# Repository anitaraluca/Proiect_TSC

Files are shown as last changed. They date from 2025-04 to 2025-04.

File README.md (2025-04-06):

# Proiect_TSC

## 📊 Diagrama Block

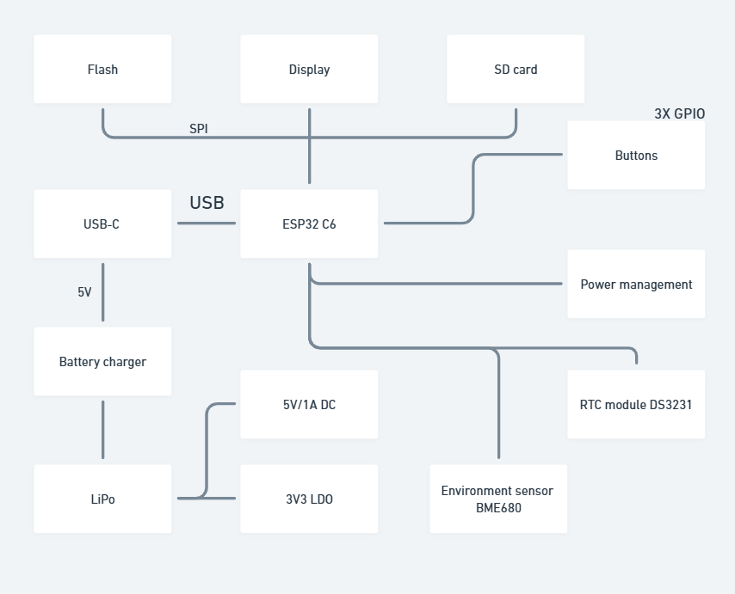
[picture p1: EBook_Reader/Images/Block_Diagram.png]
Block Diagram


---

##  Descriere Hardware

### 1. Microcontroller – ESP32-C6
- Nucleul sistemului, gestionează toate comunicațiile și logica aplicației.
- Arhitectură RISC-V 32-bit, 160 MHz
- Conectivitate: Wi-Fi 6 (2.4 GHz), Bluetooth 5.0
- GPIO: configurate pentru SPI, I2C, UART, control E-Ink

### 2. Power Management & Baterie
- Baterie Li-Po, 3.7V, 1800mAh
- Circuit de încărcare: MCP73831T
- Alimentare prin USB-C la 5V
- Protecție la supraîncărcare și descărcare profundă
- Regulator LDO 3.3V

### 3. Display – E-Ink 7.5"
- Dimensiune: 7.5 inch
- Rezoluție: 800x480 px
- Comunicare prin SPI

### 4. Port USB-C & Protecție ESD
- Alimentare și transfer de date
- Diodă Schottky și protecție ESD integrată

### 5. RTC – DS3231SN
- Păstrează ora exactă fără alimentare
- Comunicare prin I2C, include baterie de rezervă

### 6. Senzor Ambiental – BME688
- Măsoară temperatură, umiditate, presiune și calitatea aerului
- Comunicare I2C

### 7. Memorie externă – NOR Flash 64MB
- Conectată prin SPI
- Stocare extinsă pentru date și aplicații

### 8. Cititor SD Card
- Comunică prin SPI
- Permite stocare fișiere, jurnalizare și update firmware

### 9. Test Pads
- GPIO: control butoane și I/O general
- SPI: comunicare SD card, Flash și Display
- I2C: senzori și RTC
- UART: debug și serial
- Wi-Fi & Bluetooth: conectivitate wireless

---

##  Pin Mapping

| Componentă | Pini ESP32-C6 | Interfață | Funcționalitate |
|---|---|---|---|
| Butoane Control | IO9 (BOOT), IO15 (CHANGE), EN (RESET) | GPIO | Interacțiune utilizator |
| Conexiune USB-C | GPIO prin regulator | USB | Alimentare + programare ESP32 |
| Afișaj E-Paper | IO7, IO6, IO10, IO5, IO23, IO3 | SPI | Transfer date imagine + control |
| Senzor BME688 | IO21 (SDA), IO22 (SCL) | I2C | Măsurători ambientale |
| Modul RTC DS3231 | IO21 (SDA), IO22 (SCL), IO1, IO0, IO18 | I2C | Timp real |
| Flash NOR extern | IO11 (CS), IO6, IO2, IO7 | SPI | Memorie aplicație |
| Cititor MicroSD | IO7, IO6, IO4, IO2 | SPI | Stocare fișiere externe |
| Monitorizare Baterie | IO21 (SDA), IO22 (SCL) | I2C | Nivel încărcare |

---

##  Bill of Materials

| Componentă | Datasheet |  Distribuitor |
|---|---|---|
| CPH3225A | [Datasheet](https://www.snapeda.com/parts/CPH3225A/Seiko%20Instruments/datasheet/) | [Link](https://www.snapeda.com/parts/CPH3225A/Seiko+Instruments/view-part/?ref=eda) |
| TPTP20R | [Datasheet](https://cdn-shop.adafruit.com/product-files/3825/3825_diagram.PDF) | [Link](https://ro.mouser.com/ProductDetail/Adafruit/3825?qs=%252bEew9%252b0nqrAn6n76%252bB5vZg%3D%3D) |
| ESP32C6 Varistor 1812 | [Datasheet](https://www.snapeda.com/parts/RC0603JR-070RL/Yageo/datasheet/) | [Link](https://www.snapeda.com/parts/RC0603JR-070RL/Yageo/view-part/) |
| Capacitor 0402 | [Datasheet](https://componentsearchengine.com/Datasheets/2/CC0402MRX5R5BB106.pdf) | [Link](https://componentsearchengine.com/part-view/CC0402MRX5R5BB106/YAGEO) |
| USB4110-GF-A | [Datasheet](https://gct.co/files/drawings/usb4110.pdf) | [Link](https://componentsearchengine.com/part-view/USB4110-GF-A/GCT%20(GLOBAL%20CONNECTOR%20TECHNOLOGY)) |
| MBR0530 Schottky Diode | [Datasheet](https://www.snapeda.com/parts/MBR0530/ON%20Semiconductor/datasheet/) | [Link](https://www.snapeda.com/parts/MBR0530/Onsemi/view-part/?ref=eda) |
| PGB1010603MR | [Datasheet](https://www.snapeda.com/parts/PGB1010603MR/Littelfuse%20Inc./datasheet/) | [Link](https://www.snapeda.com/parts/PGB1010603MR/Littelfuse/view-part/?ref=eda) |
| MAX17048G+T10 | [Datasheet](https://www.snapeda.com/parts/MAX17048G+T10/Analog%20Devices/datasheet/) | [Link](https://www.snapeda.com/parts/MAX17048G+T10/Analog+Devices/view-part/?ref=eda) |
| QWIIC Connector | [Datasheet](https://www.snapeda.com/parts/PRT-14417/SparkFun%20Electronics/datasheet/) | [Link](https://www.snapeda.com/parts/PRT-14417/SparkFun/view-part/) |
| ESP32C6 WROOM-1-N8 | [Datasheet](https://www.snapeda.com/parts/ESP32-C6-WROOM-1-N8/Espressif%20Systems/datasheet/) | [Link](https://www.snapeda.com/parts/ESP32-C6-WROOM-1-N8/Espressif+Systems/view-part/?ref=eda) |
| RCL CPOL 3528 | [Datasheet](https://s3.amazonaws.com/snapeda/datasheet/TAJB475K025RNJ_AVX.pdf) | [Link](https://www.snapeda.com/parts/TAJB475K025RNJ/AVX/view-part/?ref=dk&t=capacitor%203528&con_ref=None) |
| 744043680 | [Datasheet](https://www.we-online.com/components/products/datasheet/744043680.pdf) | [Link](https://ro.mouser.com/ProductDetail/Wurth-Elektronik/744043680?qs=PGXP4M47uW6VkZq%252BkzjrHA%3D%3D) |
| SI1308EDL-T1-GE3 MOSFET | [Datasheet](https://www.snapeda.com/parts/SI1308EDL-T1-GE3/Vishay%20Siliconix/datasheet/) | [Link](https://www.snapeda.com/parts/SI1308EDL-T1-GE3/Vishay+Siliconix/view-part/?ref=eda) |
| DS3231SN | [Datasheet](https://www.snapeda.com/parts/DS3231SN%23/Analog%20Devices/datasheet/) | [Link](https://www.snapeda.com/parts/DS3231SN%23/Analog+Devices/view-part/?ref=eda) |
| W25Q512JVEIQ | [Datasheet](https://www.winbond.com/resource-files/W25Q512JV%20SPI%20RevB%2006252019%20KMS.pdf) | [Link](https://www.digikey.ro/en/models/10244706) |
| ESP32 WROVER MCP73831 Power Management | [Datasheet](https://www.snapeda.com/parts/MCP73831T-2ACI/OT/Microchip/datasheet/) | [Link](https://www.snapeda.com/parts/MCP73831T-2ACI/OT/Microchip/view-part/) |
| FH34SRJ-24S-0.5SH | [Datasheet](https://www.snapeda.com/parts/FH34SRJ-24S-0.5SH(99)/Hirose%20Connector/datasheet/) | [Link](https://www.snapeda.com/parts/FH34SRJ-24S-0.5SH(99)/Hirose/view-part/) |
| ESP32 WROVER BME680 Sensor | [Datasheet](https://www.bosch-sensortec.com/media/boschsensortec/downloads/datasheets/bst-bme680-ds001.pdf) | [Link](https://www.digikey.ro/en/models/7401317) |
| ESP32 WROVER 0805 Capacitor | [Datasheet](https://ro.mouser.com/datasheet/2/40/schottky-3165252.pdf) | [Link](https://ro.mouser.com/ProductDetail/KYOCERA-AVX/SD0805S020S1R0?qs=jCA%252BPfw4LHbpkAoSnwrdjw%3D%3D) |
| Custom Button | [Datasheet](https://industry.panasonic.com/global/en/downloads?tab=catalog&small_g_cd=203&part_no=EVQPUJ02K) | [Link](https://industry.panasonic.com/global/en/products/control/switch/light-touch/number/evqpuj02k) |
| 112A-TAAR-R03 | [Datasheet](https://www.snapeda.com/parts/112A-TAAR-R03/Attend/datasheet/) | [Link](https://www.snapeda.com/parts/112A-TAAR-R03/Attend/view-part/) |
| LED Chip 0603 | [Datasheet](https://www.snapeda.com/parts/KP-1608SURCK/Kingbright/datasheet/) | [Link](https://grabcad.com/library/0603-smd-led-1) |
| BD5229G-TR | [Datasheet](https://www.rohm.com/datasheet?p=BD5229G&dist=Digi-key&media=referral&source=digi-key.com&campaign=Digi-key) | [Link](https://www.digikey.ee/en/models/658502) |
| USBLC6-2SC6Y | [Datasheet](https://www.snapeda.com/parts/USBLC6-2SC6Y/STMicroelectronics/datasheet/) | [Link](https://www.snapeda.com/parts/USBLC6-2SC6Y/STMicroelectronics/view-part/?ref=eda) |
| XC6220A331MR-G | [Datasheet](https://product.torexsemi.com/system/files/series/xc6220.pdf) | [Link](https://componentsearchengine.com/part-view/XC6220A331MR-G/Torex) |
| Resistor 0402 | [Datasheet](https://www.yageo.com/upload/media/product/products/datasheet/rchip/PYu-RC_Group_51_RoHS_L_12.pdf) | [Link](https://componentsearchengine.com/part-view/R0402%201%25%20100%20K%20(RC0402FR-07100KL)/YAGEO) |

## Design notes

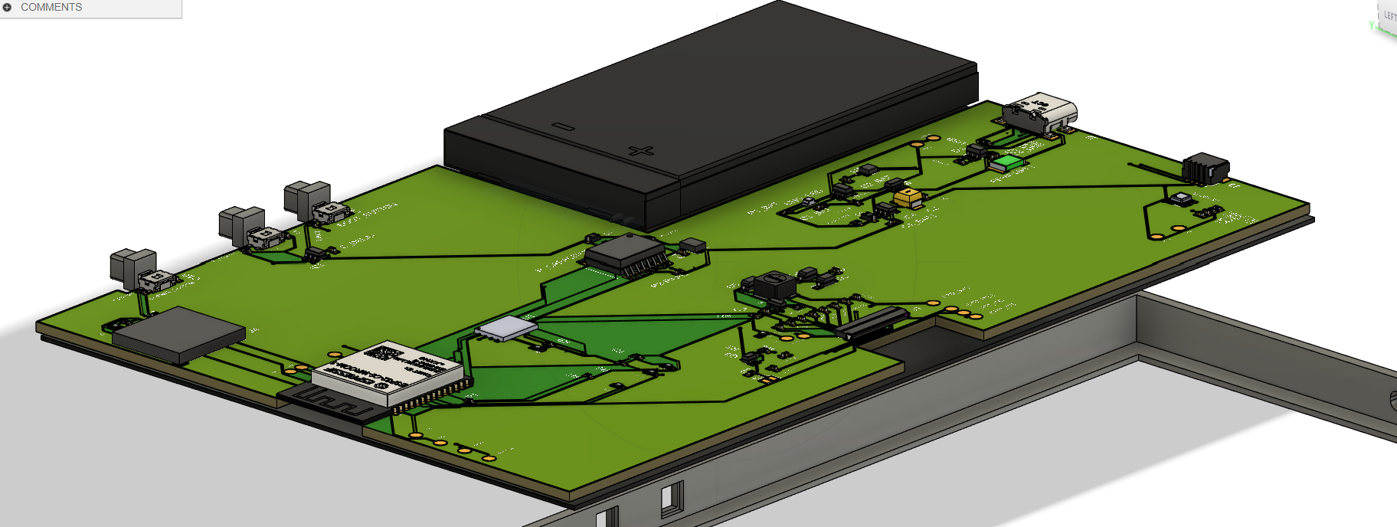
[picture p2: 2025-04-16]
EBook_Reader/Images/pcb+baterie.png

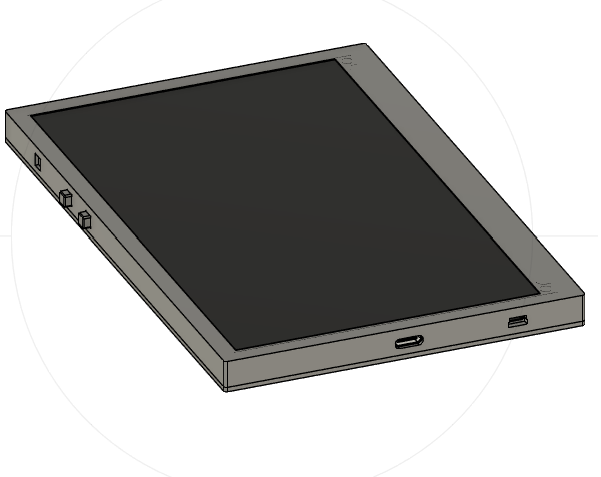
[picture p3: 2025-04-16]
EBook_Reader/Images/Fata.png

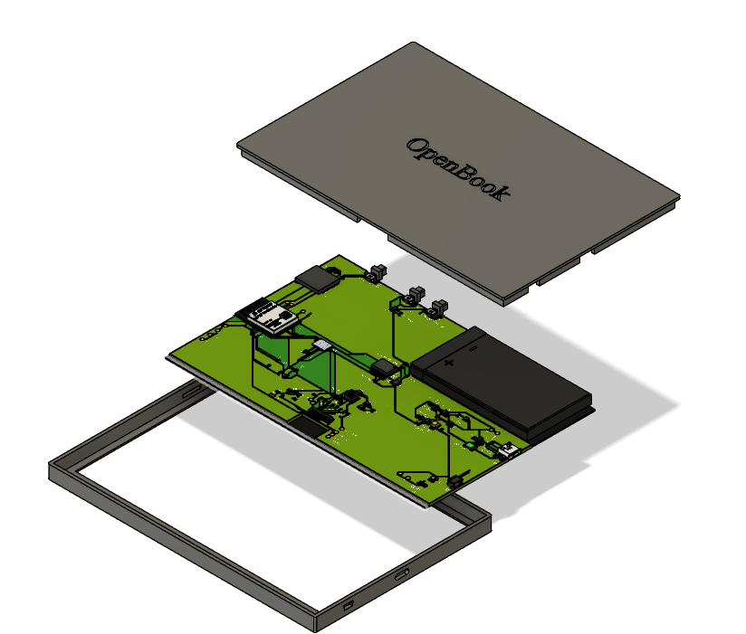
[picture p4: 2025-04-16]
EBook_Reader/Images/Exploded.png

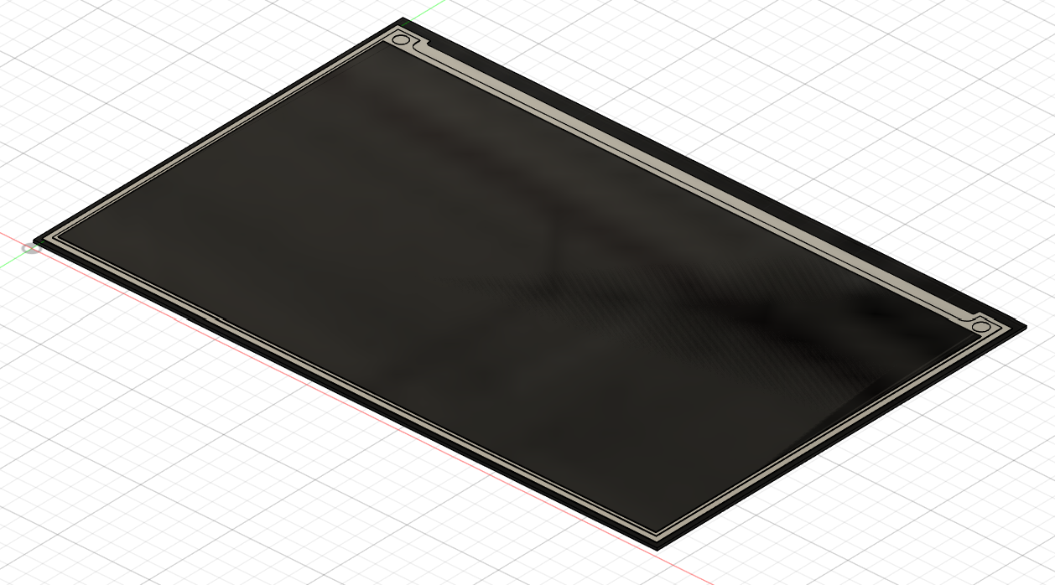
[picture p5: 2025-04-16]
EBook_Reader/Images/Display.png

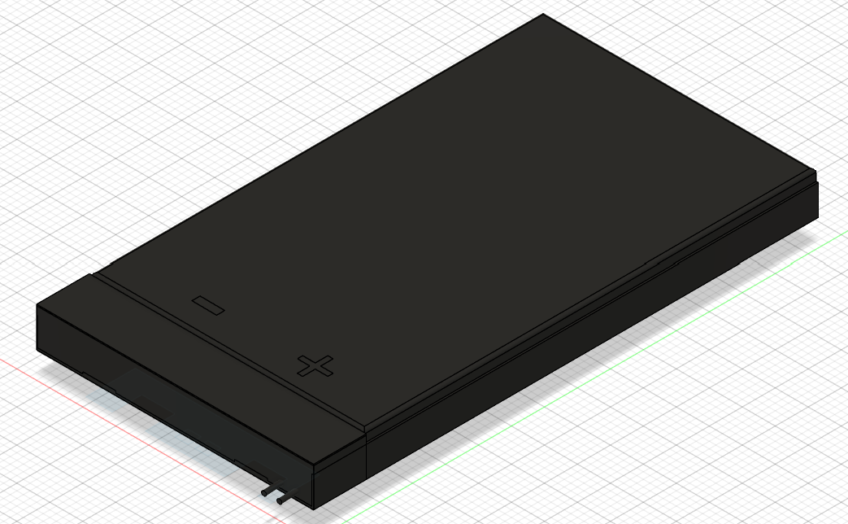
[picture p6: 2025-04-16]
EBook_Reader/Images/Baterie.png

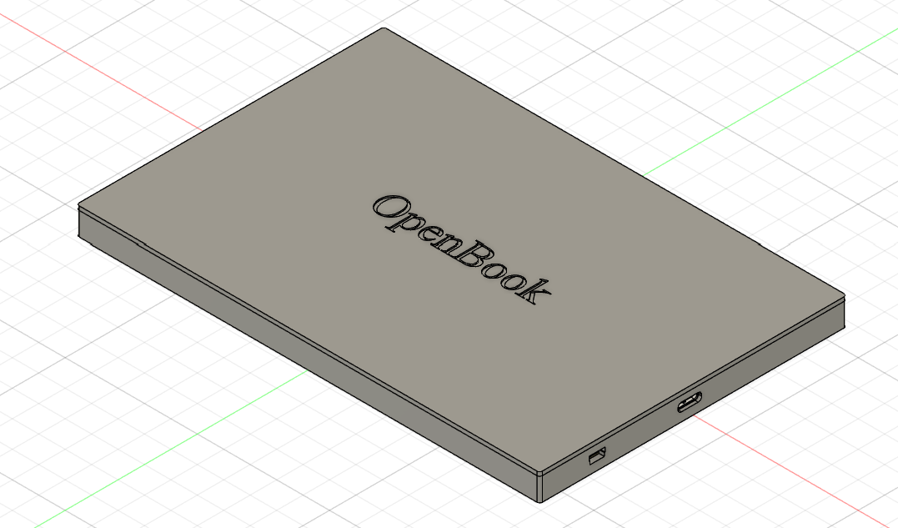
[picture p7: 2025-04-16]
EBook_Reader/Images/spate.png

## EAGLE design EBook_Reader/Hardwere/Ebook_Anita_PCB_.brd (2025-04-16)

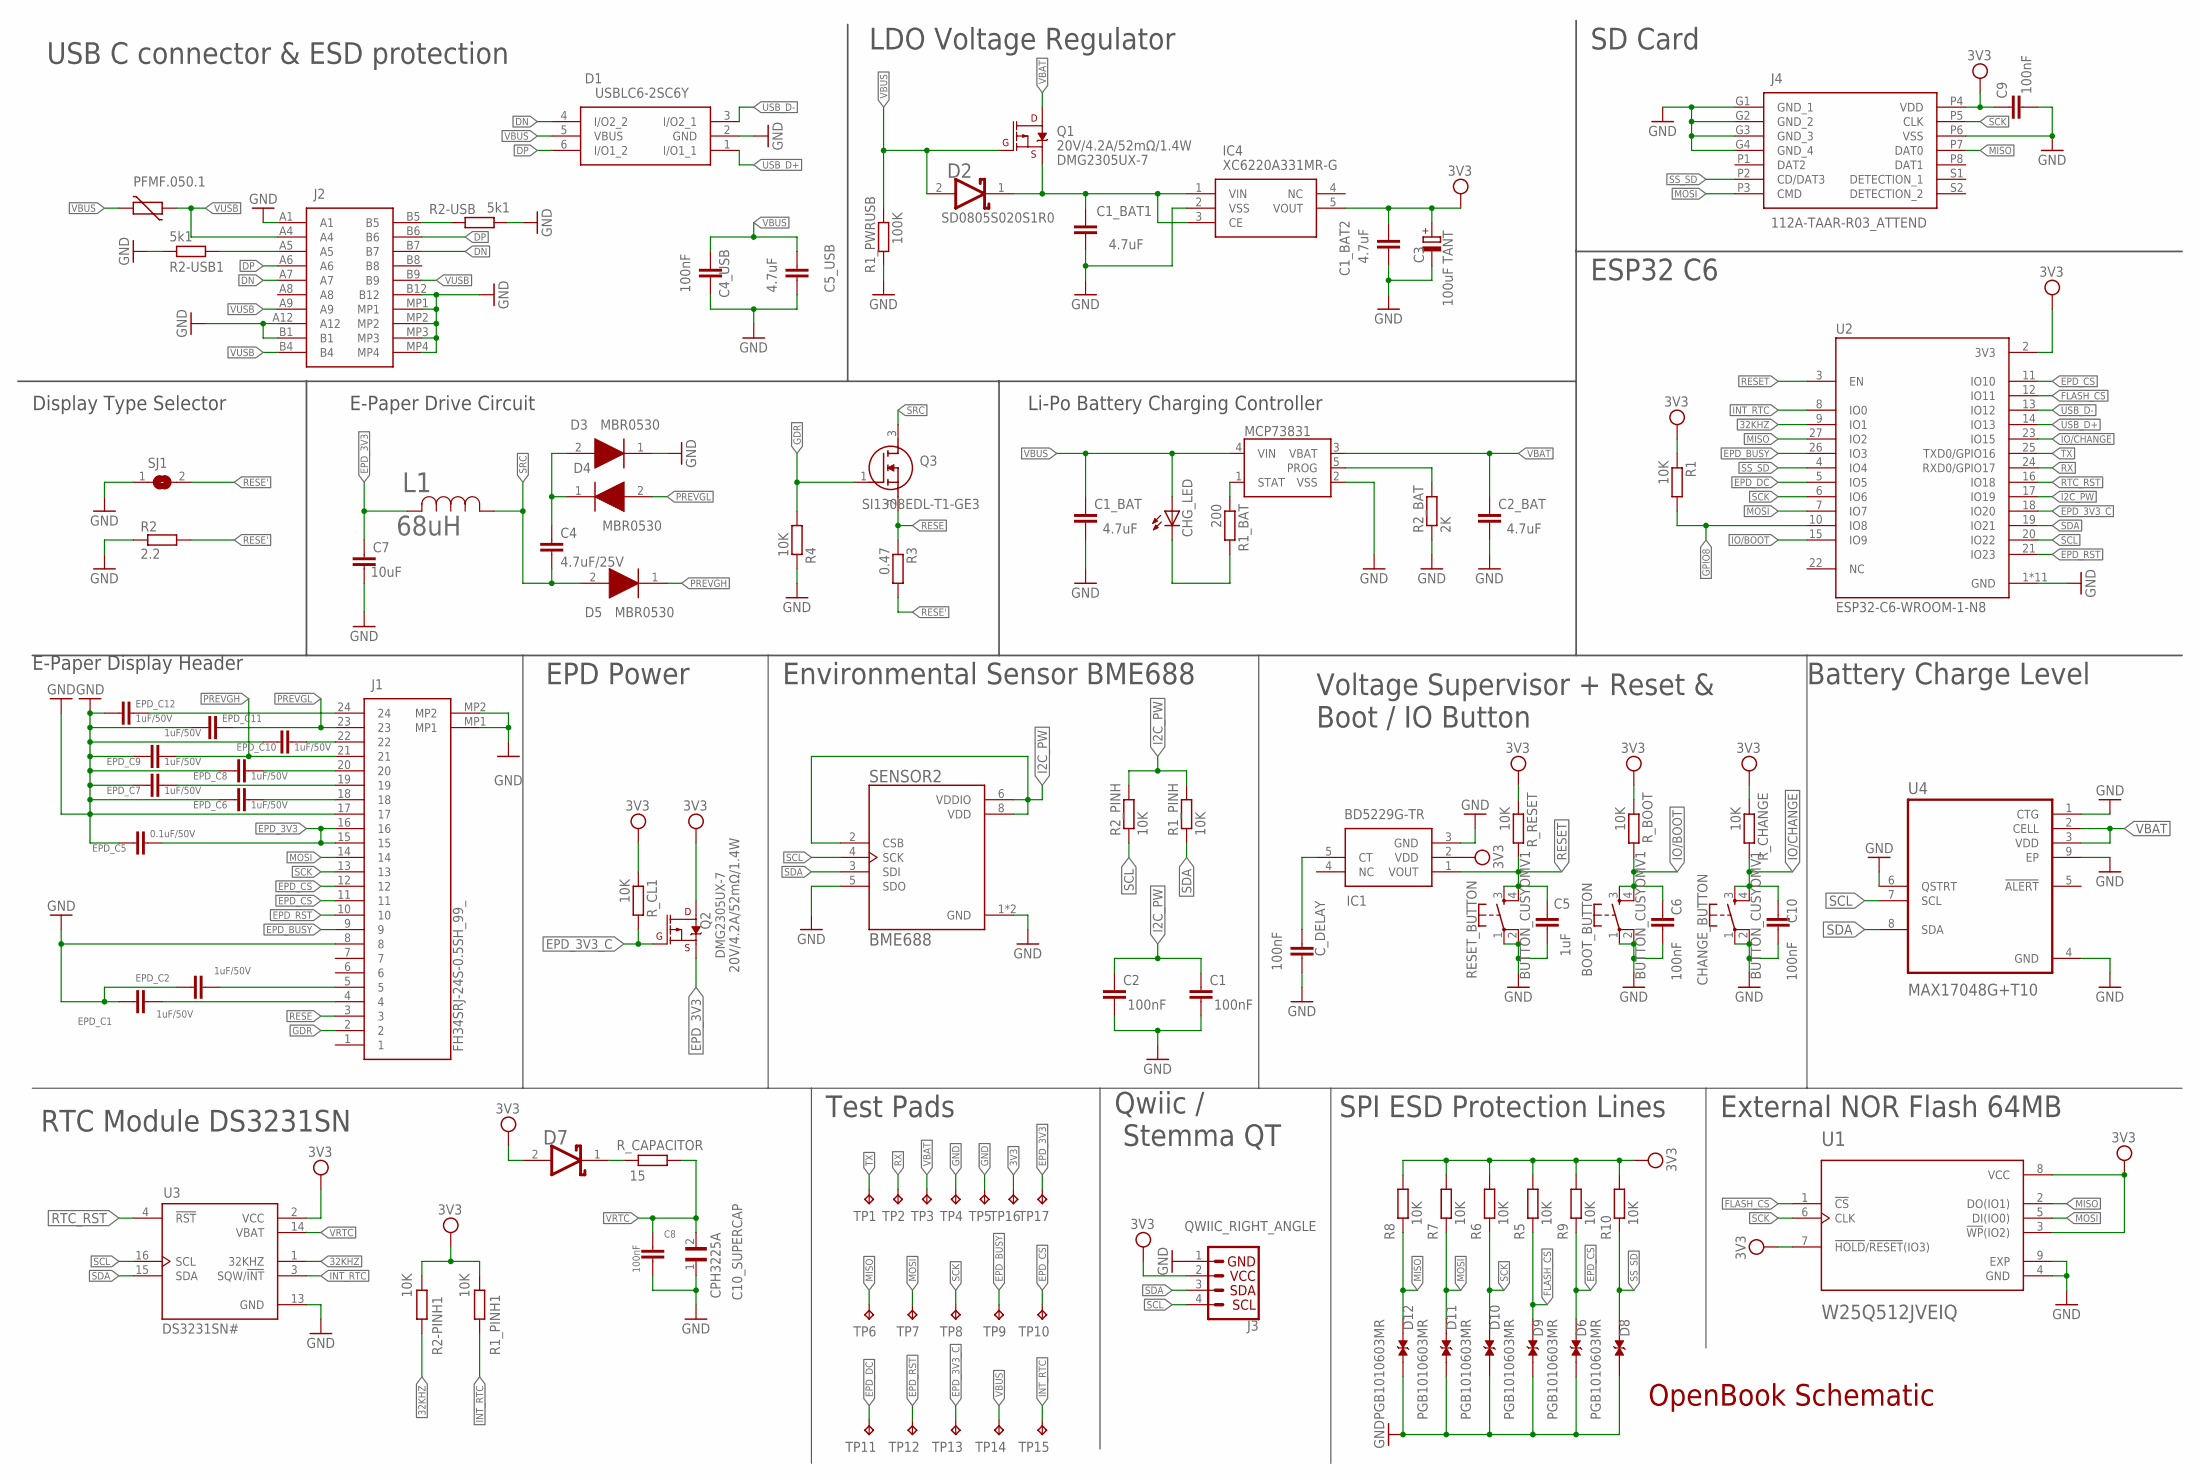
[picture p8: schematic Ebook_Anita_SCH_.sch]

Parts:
BOOT_BUTTON: BUTTON_CUSYOMV1; MYBUTTON
C1, C2, C4_USB, C6, C8, C9, C10: 100nF; ESP32_WROVER_EAGLE-LTSPICE_C0402
C1_BAT, C1_BAT1, C1_BAT2, C2_BAT, C5_USB: 4.7uF; ESP32_WROVER_EAGLE-LTSPICE_C0402
C3: 100uF TANT; RCL_CT3528
C4: 4.7uF/25V; ESP32_WROVER_EAGLE-LTSPICE_C0402
C5: 1uF; ESP32_WROVER_EAGLE-LTSPICE_C0402
C7: 10uF; ESP32_WROVER_EAGLE-LTSPICE_C0402
C10_SUPERCAP: CPH3225A; CAPCP3225X100N
CHANGE_BUTTON: BUTTON_CUSYOMV1; MYBUTTON
CHG_LED: ADAFRUIT_LEDCHIP-LED0603; ADAFRUIT_CHIP-LED0603
C_DELAY: 100nF; ESP32_WROVER_EAGLE-LTSPICE_C0402
D1: USBLC6-2SC6Y; SOT95P280X145-6N
D2, D7: ESP32_WROVER_AVX---SD0805S020S1R0_AVX_SD0805S020S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; ESP32_WROVER_AVX---SD0805S020S1R0_AVX_SD0805S020S1R0_0
D3, D4, D5: MBR0530; SOD3716X135N
D6, D8, D9, D10, D11, D12: PGB1010603MR; DIOC1608X36N
EPD_C1, EPD_C2, EPD_C6, EPD_C7, EPD_C8, EPD_C9, EPD_C10, EPD_C11, EPD_C12: 1uF/50V; ESP32_WROVER_EAGLE-LTSPICE_C0402
EPD_C5: 0.1uF/50V; ESP32_WROVER_EAGLE-LTSPICE_C0402
IC1: BD5229G-TR; SOT95P280X125-5N
IC4: XC6220A331MR-G; SOT95P280X120-5N
J1: FH34SRJ-24S-0.5SH_99_; FH34SRJ24S05SH99
J2: SAMACSYS_PARTS_USB4110-GF-A; SAMACSYS_PARTS_USB4110GFA
J3: QWIIC_RIGHT_ANGLE; JST04_1MM_RA
J4: 112A-TAAR-R03_ATTEND; 112ATAARR03ATTEND
L1: 68uH; IND_4828-WE-TPC_WRE
MCP73831: ESP32_WROVER_SPARKFUN-IC-POWER_MCP73831; ESP32_WROVER_SPARKFUN-IC-POWER_SOT23-5
PFMF.050.1: ESP32C6_VARISTORCN1812; ESP32C6_VARISTOR_CT/CN1812
Q1, Q2: 20V/4.2A/52mΩ/1.4W; ESP32_WROVER_SPARKFUN-DISCRETESEMI_SOT23-3
Q3: SI1308EDL-T1-GE3; SOT65P210X110-3N
R1, R1_PINH, R1_PINH1, R2-PINH1, R2_PINH, R4, R5, R6, R7, R8, R9, R10: 10K; ESP32_WROVER_EAGLE-LTSPICE_R0402
R1_BAT: 200; ESP32_WROVER_EAGLE-LTSPICE_R0402
R1_PWRUSB: 100K; ESP32_WROVER_EAGLE-LTSPICE_R0402
R2: 2.2; ESP32_WROVER_EAGLE-LTSPICE_R0402
R2-USB, R2-USB1: 5k1; ESP32_WROVER_EAGLE-LTSPICE_R0402
R2_BAT: 2K; ESP32_WROVER_EAGLE-LTSPICE_R0402
R3: 0.47; ESP32_WROVER_EAGLE-LTSPICE_R0402
RESET_BUTTON: BUTTON_CUSYOMV1; MYBUTTON
R_BOOT: 10K; ESP32_WROVER_EAGLE-LTSPICE_R0402
R_CAPACITOR: 15; ESP32_WROVER_EAGLE-LTSPICE_R0402
R_CHANGE: 10K; ESP32_WROVER_EAGLE-LTSPICE_R0402
R_CL1: 10K; ESP32_WROVER_EAGLE-LTSPICE_R0402
R_RESET: 10K; ESP32_WROVER_EAGLE-LTSPICE_R0402
SENSOR2: BME688; ESP32_WROVER_BME680_PSON80P300X300X100-8N
SJ1: SJ
TP1, TP2, TP3, TP4, TP5, TP6, TP7, TP8, TP9, TP10, TP11, TP12, TP13, TP14, TP15, TP16, TP17: TPTP20R; TP20R
U1: W25Q512JVEIQ; SON127P600X800X80-9N
U2: ESP32-C6-WROOM-1-N8; XCVR_ESP32-C6-WROOM-1-N8
U3: DS3231SN#; SOIC127P1032X265-16N
U4: MAX17048G+T10; SON50P200X200X80-9N

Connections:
3V3: C1_BAT2.1, C3.+, C9.1, D7.2 (ANODE), IC1.2 (VDD), IC4.5 (VOUT), J3.2, J4.P4 (VDD), Q2.3 (D), R1.1, R1_PINH1.2, R2-PINH1.2, R5.1, R6.2, R7.2, R8.2, R9.2, R10.2, R_BOOT.1, R_CHANGE.1, R_CL1.1, R_RESET.1, TP16.TP, U1.3 (!WP!(IO2)), U1.7 (!HOLD!/!RESET!(IO3)), U1.8 (VCC), U2.2 (3V3), U3.2 (VCC)
32KHZ: R2-PINH1.1, U2.9 (IO1), U3.1 (32KHZ)
DN: D1.4 (I/O2_2), J2.A7, J2.B7
DP: D1.6 (I/O1_2), J2.A6, J2.B6
EPD_3V3: C7.1, EPD_C5.1, J1.15, J1.16, L1.2, Q2.2 (S), TP17.TP
EPD_3V3_C: Q2.1 (G), R_CL1.2, TP13.TP, U2.18 (IO20)
EPD_BUSY: J1.9, TP9.TP, U2.26 (IO3)
EPD_CS: D6.1, J1.11, J1.12, R9.1, TP10.TP, U2.11 (IO10)
EPD_DC: TP11.TP, U2.5 (IO5)
EPD_RST: J1.10, TP12.TP, U2.21 (IO23)
FLASH_CS: D9.1, R5.2, U1.1 (!CS), U2.12 (IO11)
GDR: J1.2, Q3.1 (G), R4.1
GND: BOOT_BUTTON.1, BOOT_BUTTON.2, C1.2, C1_BAT.2, C1_BAT1.2, C1_BAT2.2, C2.2, C2_BAT.2, C3.-, C4_USB.2, C5.2, C5_USB.2, C6.2, C7.2, C8.2, C9.2, C10.2, C10_SUPERCAP.1, CHANGE_BUTTON.1, CHANGE_BUTTON.2, C_DELAY.2, D1.2 (GND), D3.1 (K), D6.2, D8.2, D9.2, D10.2, D11.2, D12.2, EPD_C1.2, EPD_C2.2, EPD_C5.2, EPD_C6.2, EPD_C7.2, EPD_C8.2, EPD_C9.2, EPD_C10.2, EPD_C11.2, EPD_C12.2, IC1.3 (GND), IC4.2 (VSS), J1.8, J1.17, J1.MP1, J1.MP2, J2.A1, J2.A12, J2.B1, J2.B12, J2.MP1, J2.MP2, J2.MP3, J2.MP4, J3.1, J4.G1 (GND_1), J4.G2 (GND_2), J4.G3 (GND_3), J4.G4 (GND_4), J4.P6 (VSS), MCP73831.2 (VSS), R1_PWRUSB.1, R2.1, R2-USB.2, R2-USB1.1, R2_BAT.1, R4.2, RESET_BUTTON.1, RESET_BUTTON.2, SENSOR2.1 (GND), SENSOR2.5 (SDO), SENSOR2.7 (GND), SJ1.1, TP4.TP, TP5.TP, U1.4 (GND), U1.9 (EXP), U2.1 (GND), U2.28 (GND), U2.29_1 (GND), U2.29_2 (GND), U2.29_3 (GND), U2.29_4 (GND), U2.29_5 (GND), U2.29_6 (GND), U2.29_7 (GND), U2.29_8 (GND), U2.29_9 (GND), U3.13 (GND), U4.1 (CTG), U4.4 (GND), U4.6 (QSTRT), U4.9 (EP)
GPIO8: R1.2, U2.10 (IO8)
I2C_PW: C1.1, C2.1, R1_PINH.2, R2_PINH.2, SENSOR2.2 (CSB), SENSOR2.6 (VDDIO), SENSOR2.8 (VDD), U2.17 (IO19)
INT_RTC: R1_PINH1.1, TP15.TP, U2.8 (IO0), U3.3 (SQW/!INT)
IO/BOOT: BOOT_BUTTON.3, BOOT_BUTTON.4, C6.1, R_BOOT.2, U2.15 (IO9)
IO/CHANGE: C10.1, CHANGE_BUTTON.3, CHANGE_BUTTON.4, R_CHANGE.2, U2.23 (IO15)
MISO: D12.1, J4.P7 (DAT0), R8.1, TP6.TP, U1.2 (DO(IO1)), U2.27 (IO2)
MOSI: D11.1, J1.14, J4.P3 (CMD), R7.1, TP7.TP, U1.5 (DI(IO0)), U2.7 (IO7)
unnamed: J2.B5, R2-USB.1
unnamed: C1_BAT1.1, D2.1 (CATHODE), IC4.1 (VIN), IC4.3 (CE), Q1.2 (S)
unnamed: C4.1, D3.2 (A), D4.1 (K)
unnamed: J2.A5, R2-USB1.2
unnamed: D7.1 (CATHODE), R_CAPACITOR.2
unnamed: CHG_LED.C, R1_BAT.2
unnamed: MCP73831.5 (PROG), R2_BAT.2
unnamed: MCP73831.1 (STAT), R1_BAT.1
unnamed: EPD_C12.1, J1.24
unnamed: C_DELAY.1, IC1.5 (CT)
unnamed: EPD_C10.1, J1.22
unnamed: EPD_C8.1, J1.20
unnamed: EPD_C7.1, J1.19
unnamed: EPD_C6.1, J1.18
unnamed: EPD_C2.1, J1.5
unnamed: EPD_C1.1, J1.4
PREVGH: D5.1 (K), EPD_C9.1, J1.21
PREVGL: D4.2 (A), EPD_C11.1, J1.23
RESE: J1.3, Q3.2 (S), R3.1
RESE': R2.2, R3.2, SJ1.2
RESET: C5.1, IC1.1 (VOUT), RESET_BUTTON.3, RESET_BUTTON.4, R_RESET.2, U2.3 (EN)
RTC_RST: U2.16 (IO18), U3.4 (!RST)
RX: TP2.TP, U2.24 (RXD0/GPIO17)
SCK: D10.1, J1.13, J4.P5 (CLK), R6.1, TP8.TP, U1.6 (CLK), U2.6 (IO6)
SCL: J3.4, R2_PINH.1, SENSOR2.4 (SCK), U2.20 (IO22), U3.16 (SCL), U4.7 (SCL)
SDA: J3.3, R1_PINH.1, SENSOR2.3 (SDI), U2.19 (IO21), U3.15 (SDA), U4.8 (SDA)
SRC: C4.2, D5.2 (A), L1.1, Q3.3 (D)
SS_SD: D8.1, J4.P2 (CD/DAT3), R10.1, U2.4 (IO4)
TX: TP1.TP, U2.25 (TXD0/GPIO16)
USB_D+: D1.1 (I/O1_1), U2.14 (IO13)
USB_D-: D1.3 (I/O2_1), U2.13 (IO12)
VBAT: C2_BAT.1, MCP73831.3 (VBAT), Q1.3 (D), TP3.TP, U4.2 (CELL), U4.3 (VDD)
VBUS: C1_BAT.1, C4_USB.1, C5_USB.1, CHG_LED.A, D1.5 (VBUS), D2.2 (ANODE), MCP73831.4 (VIN), PFMF.050.1.2, Q1.1 (G), R1_PWRUSB.2, TP14.TP
VRTC: C8.1, C10_SUPERCAP.2, R_CAPACITOR.1, U3.14 (VBAT)
VUSB: J2.A4, J2.A9, J2.B4, J2.B9, PFMF.050.1.1

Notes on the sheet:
USB C connector & ESD protection
LDO Voltage Regulator
SD Card
ESP32 C6
E-Paper Display Header
RTC Module DS3231SN
Test Pads
Qwiic / Stemma QT
SPI ESD Protection Lines
External NOR Flash 64MB
Battery Charge Level
Voltage Supervisor + Reset & Boot / IO Button
Environmental Sensor BME688
EPD Power
OpenBook Schematic
Li-Po Battery Charging Controller
E-Paper Drive Circuit
Display Type Selector

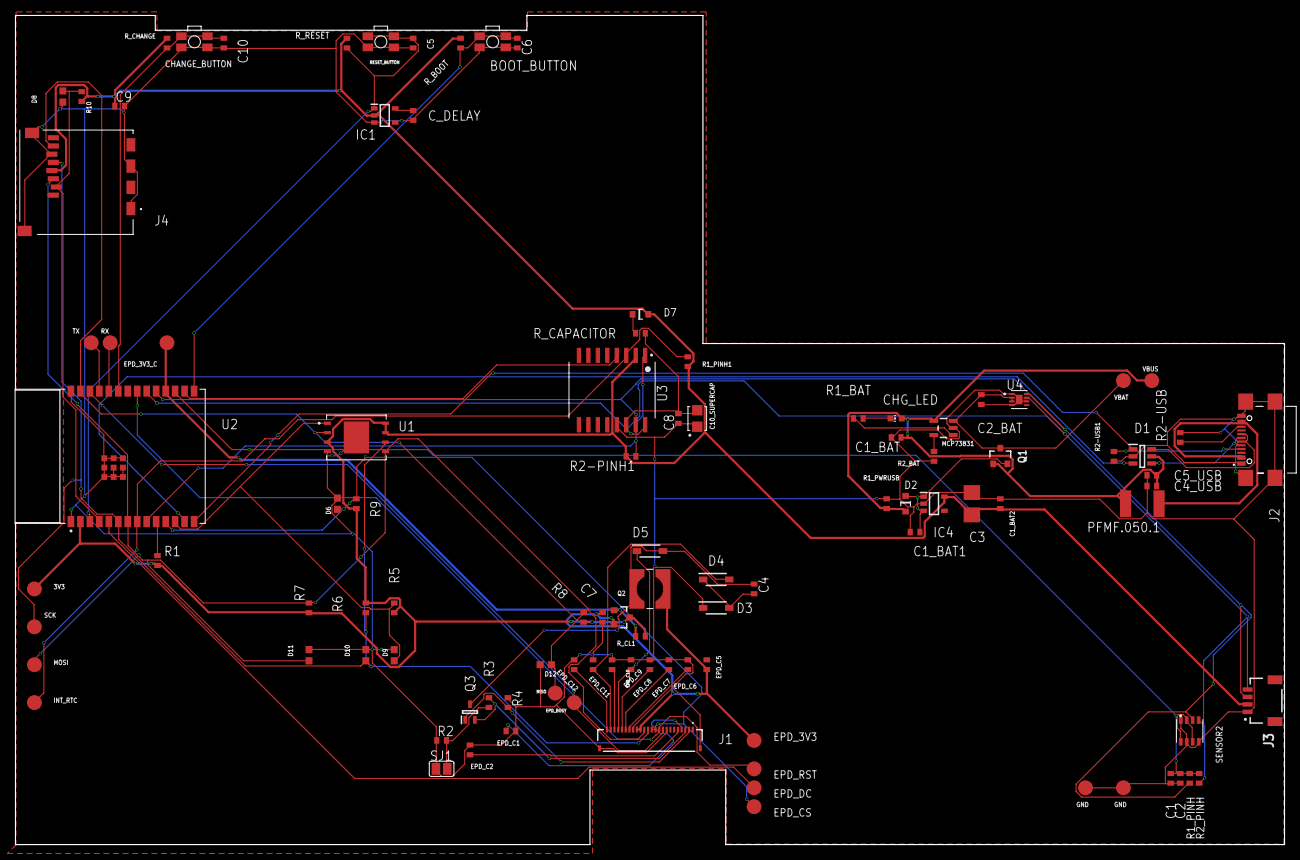
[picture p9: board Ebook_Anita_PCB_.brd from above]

Board: 2 copper layers, 170.2 x 111.2 mm, 103 parts (0 on the bottom side), 55 nets.

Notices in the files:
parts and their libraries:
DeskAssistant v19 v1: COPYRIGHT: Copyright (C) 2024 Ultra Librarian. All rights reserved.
